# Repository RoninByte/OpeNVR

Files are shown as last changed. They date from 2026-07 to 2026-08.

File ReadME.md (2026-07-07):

BOARD STATUS: In Production

Photo's of the PCB;







Features:

M-Key M.2 PCIe Gen 3 X2 Slot

E-Key M.2 PCIe Gen 3 X1 Slot

2x 2.5GBe Ethernet Ports (Realtek's RTL8125BG-CG)

4x Molex Mini-Fit Jr for powering upto 3.5" Sata drives

5v Fan header for the built in fan on the Lattepanda MU

12v Fan Header for a system fan

HDMI 2.1

2x USB 3.2 Gen 2

2x USB 2.0

DDR4 SO-DIMM Slot for Lattepanda MU (Many options to choose from)

Uses Nano-ITX Standard

20v USB-C PD Input.

Dual Bios to switch between MU Bios and Your own Custom Bios

6x Sata Ports (ASM1166)

* 2 Sata ports will remain unpopulated however they will be connected to the IC incase you want to add more ports

Sata Ports LED (Once again optional)

Any Suggestions Just Open an Issue and i'll take a look

Credits:

EShark 

WifiCable for improvements and fixes

Lattepanda Team For Lattepanda MU Lite Kit

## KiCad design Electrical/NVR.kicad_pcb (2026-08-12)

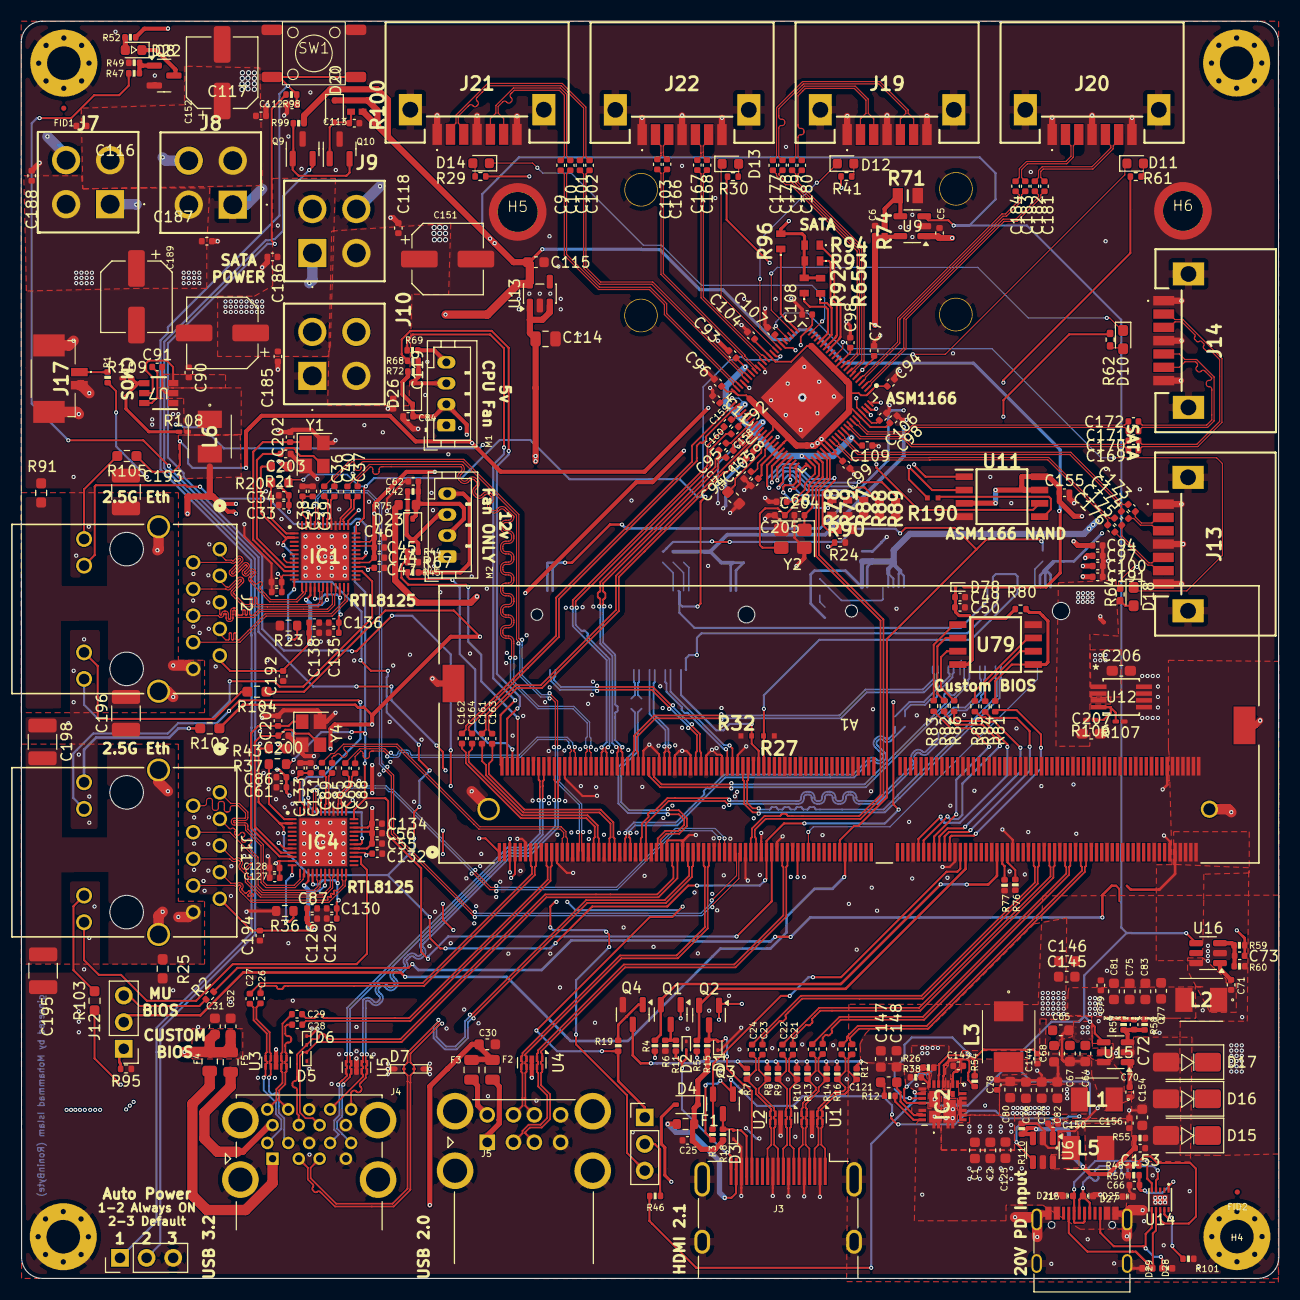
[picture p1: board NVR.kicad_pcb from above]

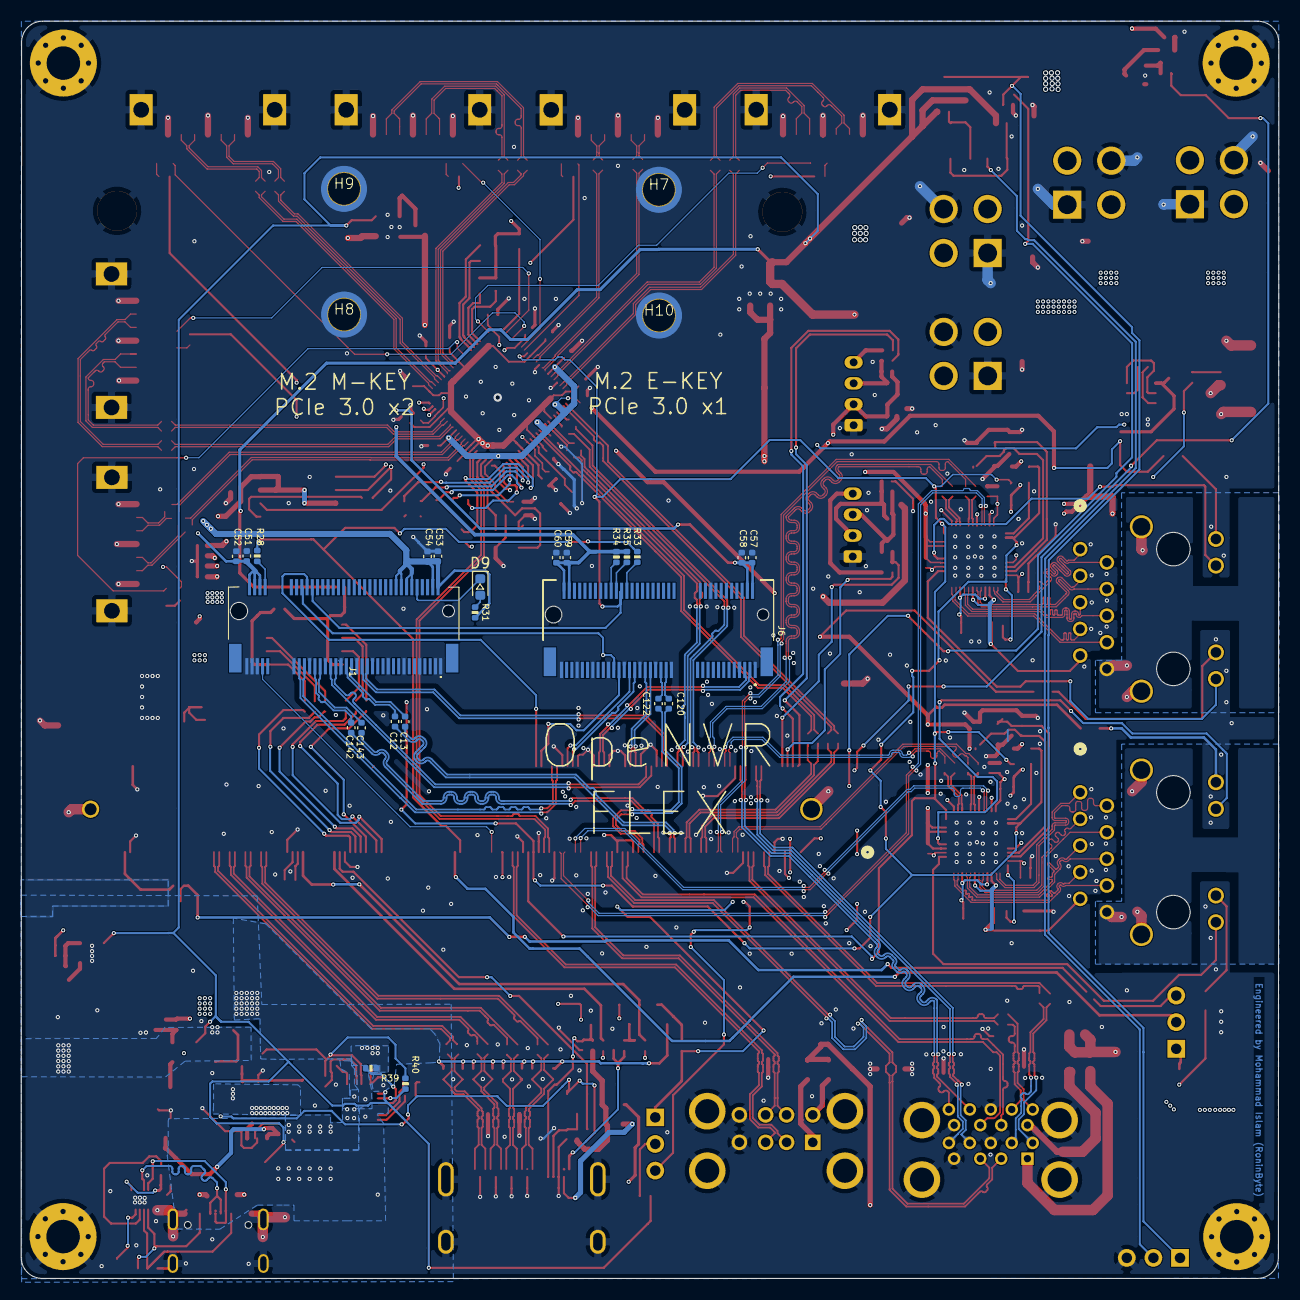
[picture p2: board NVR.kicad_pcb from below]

Board: 4 copper layers, 120.0 x 120.0 mm, 400 parts (28 on the bottom side), 317 nets.

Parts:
A1: TE Connectivity 2309413-1 DDR4 SODIMM H9.2mm; CONN260_2309413-1_TEC
C1, C2, C64, C65, C67, C68, C121: 22uF/50V; C_0603_1608Metric
C5, C6, C66, C112: 1uF/16V; C_0402_1005Metric
C7, C8, C11, C17, C18, C19, C20, C21, C22, C23, C24, C25, C26, C27, C28, C29, C52, C54, C58, C60, C62, C70, C71, C78, C79, C84, C91, C92, C93, C94#3, C106, C107, C108, C109, C116, C117, C118, C119, C150, C156, C185, C186, C187, C188: 100nF/50V; C_0402_1005Metric
C9, C103, C166, C167, C168, C169, C170, C171, C172, C173, C174, C175, C176, C177, C178, C179, C180, C181, C182, C183, C184: 10nF/20V; C_0402_1005Metric
C10, C101, C102: 10nF; C_0402_1005Metric
C12, C13, C120, C122, C142, C143: 220nF/50V; C_0402_1005Metric
C30, C31, C32, C74, C75, C76, C77, C80, C81, C82, C83: 22uF/10V; C_0603_1608Metric
C33, C34, C35, C36, C37, C38, C39, C40, C41, C42, C44, C45, C46, C47, C55, C56, C61, C69, C85, C86, C88, C89, C134, C135, C136, C137, C138, C192, C194: 100nF/50v; C_0402_1005Metric
C49: 22uF/6.3V; C_0402_1005Metric
C50: 0.1uF/16V; C_0402_1005Metric
C51, C53, C57, C59, C94, C94#2, C95, C96, C97, C98#2, C99, C100, C104, C113, C127, C128, C129, C130, C131, C133, C191: 10uF/10V; C_0402_1005Metric
C72, C73, C153: 12pF/50V; C_0402_1005Metric
C87, C98, C105, C126, C132: C; C_0402_1005Metric
C90: 10uF/50V; C_0402_1005Metric
C114: 10uF/50V; C_0805_2012Metric
C115: 10u/F10V; C_0603_1608Metric
C125: 100nF/50V; C_0603_1608Metric
C144: 1uF/25V; C_0402_1005Metric
C145, C146, C147, C148: 47uF; C_0603_1608Metric
C149: 4.7uF/25V; C_0402_1005Metric
C151, C152: 220uF/50V; CP_Elec_6.3x7.7
C154: 22uF/25V; C_0603_1608Metric
C155: 100uF/6.3V; C_0402_1005Metric
C157, C158, C159, C160, C161, C162, C163, C164: 220nF/10V; C_0402_1005Metric
C165: 4.7uF/1%; C_0603_1608Metric
C189, C190: 100uF/25V; CP_Elec_6.3x7.7
C193, C195, C196, C198: 2.2nF/2kv; C_1210_3225Metric_Pad1.33x2.70mm_HandSolder
C200, C201, C202, C203, C204, C205: 22pF/20V; C_0402_1005Metric
C206, C207: 2.2uF/25V; C_0603_1608Metric_Pad1.08x0.95mm_HandSolder
D1, D2, D3, D5, D6, D7, D8: ESD5V0B03; D_SOD-923
D4, D20, D23, D26: 1N5819WS; D_SOD-323
D9, D11, D12, D13, D14, D22: LED_G; LED_0603_1608Metric
D10, D18: LED_G; LED_0603_1608Metric_Pad1.05x0.95mm_HandSolder
D15, D16, D17: SS54; D_SMA
D21, D25: ESD5V0B03; D_0402_1005Metric
D27, D28, D29: PESD24VS1UL-N; D_0402_1005Metric
D78: D_Schottky; D_SOD-923
F1: 6V/50mA; R_0603_1608Metric
F2, F3: 6V/1A; Fuse_0805_2012Metric
F4: 6V/2A; R_0805_2012Metric
F5: 6V/2A; Fuse_0805_2012Metric
FID1, FID2: Fiducial; Fiducial_0.5mm_Mask1mm
H1, H2, H3, H4: MountingHole_Pad; MountingHole_3.2mm_M3_Pad_Via
H5, H6: MountingHole_Pad; MountingHole_3mm_M2_Pad_TopOnly
H7, H8, H9, H10: MountingHole_M2.0; MountingHole_3mm_M2_Pad_TopOnly
IC1, IC4: RTL8125BG-CG; QFN40P600X600X100-49N
IC2: SiC437AED-T1-GE3; SIC437DEDT1GE3
J1: Bus_M.2_Socket_M; PCIe_M.2_Connectors_P=0.5mm_H=4.2mm_KeyM
J2, J11: ARJM11A1-805-AB-EW2; ARJM11A1-805-AB-EW2_ABR
J3: HDMI_A; HDMI_A_Molex_208658-1001_Horizontal
J4: USB3_A_Stacked; USB3_A_Molex_48406-0001_Horizontal_Stacked
J5: USB_A_Stacked; USB_A_CUI_UJ2-ADH-TH_Horizontal_Stacked
J6: Bus_M.2_Socket_E; PCIe_M.2_Connectors_P=0.5mm_H=4.2mm_KeyE
J7, J8, J9, J10: 87427-0442; 874270442
J12, J15: Conn_01x03_Pin; PinHeader_1x03_P2.54mm_Vertical
J13, J14, J19, J20, J21, J22: SATA-A-PL-SMT-K; SATAAPLSMTK
J16: USB_C_Receptacle_USB2.0; USB_C_Receptacle_G-Switch_GT-USB-7010ASV
J17: 53261-0271; 532610271
JP1: Jumper_3_Bridged12; PinHeader_1x03_P2.54mm_Vertical
L1, L2, L5, L6: 2.2uH/4.3A; SPM4010-4020
L3: 1.5uH/14A; ETQ-P3M_KVP
M1, M2: Fan_4pin; JST_PH_B4B-PH-K_1x04_P2.00mm_Vertical
Q1, Q8, Q9, Q10: 2N7002; SOT-23
Q2, Q3, Q4: 2SK3018; SOT-23
R1, R11, R47, R50: 1K/1%; R_0402_1005Metric
R2, R34, R35, R48, R49, R54, R58, R60, R95, R110: 10K/1%; R_0402_1005Metric
R3, R5, R12, R15, R18, R19, R29, R30, R31, R41, R52, R61: 2.2K/1%; R_0402_1005Metric
R4: 1M/1%; R_0402_1005Metric
R6, R44, R67, R68: 21.5K/1%; R_0402_1005Metric
R7, R8, R9, R10, R13, R14, R16, R17: 470R/1%; R_0402_1005Metric
R20, R37: 1K/1%; R_0603_1608Metric
R21, R43: 4.7K/1%; R_0603_1608Metric
R23, R36: 2.49K/1%; R_0603_1608Metric
R24: RC0402FR-075KL; R_0402_1005Metric
R25, R91: 1M/1%; R_0603_1608Metric_Pad0.98x0.95mm_HandSolder
R26: 1.0K/1%; R_0402_1005Metric
R27, R32, R190: ERA-2AEB3321X; ERA2AED122X
R28, R33: 0R/1%; R_0402_1005Metric
R38: 19.1K/1%; R_0402_1005Metric
R39: 200K/1%; R_0402_1005Metric
R40: 499K/1%; R_0402_1005Metric
R42, R72: 4.7K/1%; R_0402_1005Metric
R45, R46, R69, R98: 100R/1%; R_0402_1005Metric
R55: 240K/1%; R_0402_1005Metric
R57: 75K/1%; R_0402_1005Metric
R59: 45K/1%; R_0402_1005Metric
R62, R64: 2.2K/1%; R_0402_1005Metric_Pad0.72x0.64mm_HandSolder
R65, R78, R79, R87, R88, R89, R90, R92, R93, R94, R96: ERA-3AED162V; ERA3AEB101V
R71: CPF0805B25KE1; RESC2012X65N
R74: CRCW040250K0FKED; RESC1005X40N
R75: 0R/1%; R_0603_1608Metric
R76, R77, R99: 100K/1%; R_0402_1005Metric
R80, R101: 120K/1%; R_0402_1005Metric
R81: 0R; R_0402_1005Metric
R82, R83, R84, R85, R86: 15R/1%; R_0402_1005Metric
R100: RC0402FR-071ML; RESC1005X40N
R102, R103, R104, R105: 1k/1%; R_0603_1608Metric_Pad0.98x0.95mm_HandSolder
R106: 3.16K/1%; R_0201_0603Metric_Pad0.64x0.40mm_HandSolder
R107, R109: 10.1K/1%; R_0201_0603Metric_Pad0.64x0.40mm_HandSolder
R108: 2.37K/1%; R_0201_0603Metric_Pad0.64x0.40mm_HandSolder
SW1: SW_Push; SW_Push_6x6x6
U1, U2: TPAZ1023-04F; Diodes_UDFN-10_1.0x2.5mm_P0.5mm
U3, U4, U5: ULC0524P; Diodes_UDFN-10_1.0x2.5mm_P0.5mm
U6, U15, U16: SY8253ADC; TSOT-23-6
U7: TPS562201DDCR; DDC0006A_N
U8: ASM1166; QFN-88_L10.0-W10.0-P0.40-BL-EP5.6
U9: SOT-23-5
U11, U79: W25Q128JVSIQ; SOIC127P790X216-8N
U12: ADP1715ARMZ-R7; RM_8_ADI
U13: NCP718xSN300; SOT-23-5
U14: CH224Q_C46061833; DFN-10_L2.0-W2.0-P0.40-BL-EP
Y1, Y2, Y4: 25MHz; Crystal_SMD_3225-4Pin_3.2x2.5mm

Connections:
5V_HDMI_VCC: C25.1, D4.1 (K), F1.1, R15.1, R18.1
+0V9: C35.2, C38.2, C41.2, C42.2, C47.2, C127.2, C128.2, C129.1, C130.1, C131.2, C132.2, C133.2, C135.1, C136.1, IC1.8 (DVDD09_1), IC1.11 (AVDD09_1), IC1.16 (AVDD09_2), IC1.22 (AVDD09_3), IC1.28 (DVDD09_2), IC1.37 (EVDD09), IC1.47 (DVDD09_3), IC4.8 (DVDD09_1), IC4.11 (AVDD09_1), IC4.16 (AVDD09_2), IC4.22 (AVDD09_3), IC4.28 (DVDD09_2), IC4.37 (EVDD09), IC4.47 (DVDD09_3), L6.2
+1V0: C94.2, C94#2.2, C94#3.2, C95.2, C96.2, C97.2, C98.2, C98#2.2, C99.2, C100.2, C104.2, C191.2, C207.1, R106.2, U8.1 (VDD105), U8.11 (VDD105), U8.32 (VDD105), U8.44 (VDD105), U8.50 (VDD105), U8.56 (VDD105), U8.60 (VDD105), U8.73 (VDD105), U8.74 (VDD105), U8.84 (VDD105), U12.3 (OUT)
+2V5: C6.1, C7.2, C8.2, C11.2, C92.2, C93.1, C109.2, R74.1, U8.6 (VCC25), U8.38 (VCC25), U8.47 (VCC25P), U8.53 (VCC25P), U8.68 (VCC25CK), U8.79 (VCC25), U9.5 (VOUT)
+3V3: C5.2, C33.2, C34.2, C44.2, C45.2, C46.2, C51.2, C52.2, C53.2, C54.2, C55.2, C56.2, C57.2, C58.2, C59.2, C60.2, C61.2, C73.1, C75.2, C77.2, C79.1, C81.2, C83.2, C86.2, C87.1, C105.2, C106.2, C107.2, C108.2, C126.1, C134.2, C137.1, C138.1, C155.1, C192.2, C194.2, C206.1, IC1.15 (AVDD33_1), IC1.19 (AVDD33_2), IC1.29 (DVDD33_1), IC1.33 (AVDD33_3), IC1.34 (AVDD33_XTAL), IC1.43 (EVDD33), IC1.46 (DVDD33_2), IC4.15 (AVDD33_1), IC4.19 (AVDD33_2), IC4.29 (DVDD33_1), IC4.33 (AVDD33_3), IC4.34 (AVDD33_XTAL), IC4.43 (EVDD33), IC4.46 (DVDD33_2), J1.2 (3.3V), J1.4 (3.3V), J1.12 (3.3V), J1.14 (3.3V), J1.16 (3.3V), J1.18 (3.3V), J1.70 (3.3V), J1.72 (3.3V), J1.74 (3.3V), J2.9 (VCC), J6.2 (3.3V), J6.4 (3.3V), J6.72 (3.3V), J6.74 (3.3V), J11.9 (VCC), L2.2, Q1.1 (G), Q2.1 (G), Q3.1 (G), R3.1, R4.1, R5.1, R29.2, R30.2, R31.2, R34.2, R35.1, R41.2, R52.2, R59.2, R61.2, R62.2, R64.2, R65.2, R92.2, R93.2, R94.2, R96.2, R102.1, R103.1, R104.1, R105.1, U8.22 (VCC33), U8.28 (VCC33), U8.58 (VCC33), U8.85 (VCC33), U9.1 (VIN), U11.3 (IO2), U11.7 (IO3), U11.8 (VCC), U12.1 (EN), U12.2 (IN)
+3V3_SB: C115.1, D20.1 (K), D78.2 (A), IC2.19 (EN), R21.1, R43.1, R46.2, R99.2, R100.2, U6.4 (EN), U9.3 (EN), U13.5 (OUT), U15.4 (EN), U16.4 (EN)
+5V: C30.2, C31.2, C32.2, C72.1, C74.2, C76.2, C78.1, C80.2, C82.2, C84.1, C90.2, C185.1, C186.1, C187.1, C188.1, C189.1, C190.1, D4.2 (A), D26.1 (K), F2.1, F3.1, F4.1, F5.1, J7.2, J8.2, J9.2, J10.2, L1.2, M1.2 (+), R57.2, R72.1, U7.3 (VIN), U7.5 (EN)
+12V: C116.1, C117.1, C118.1, C119.1, C145.1, C146.1, C147.1, C148.1, C151.1, C152.1, IC2.18 (VOUT), J7.3, J8.3, J9.3, J10.3, L3.1, R38.2, R75.2
+15V: C153.1, C154.2, C156.1, D15.2 (A), D16.2 (A), D17.2 (A), L5.2, R55.2
+20V: C1.1, C2.1, C114.1, C125.1, D27.1 (K), IC2.1 (VIN_1), IC2.2 (VIN_2), IC2.22 (VIN_3), IC2.26 (VIN_4), J16.A4 (VBUS), J16.A9 (VBUS), J16.B4 (VBUS), J16.B9 (VBUS), R48.1, R50.1, U6.5 (VIN), U13.1 (IN), U13.3 (EN)
+BATT: A1.115 (VBAT), R1.1
/BIOS/SPI-CS: A1.165 (~SPI_CS), R81.1
/BIOS/SPI-IO0: A1.159 (SPI_MOSI/SPI_IO0), R83.1
/BIOS/SPI-IO1: A1.163 (SPI_MISO/SPI_IO1), R84.1
/BIOS/SPI-IO2: A1.161 (SPI_IO2), R85.1
/BIOS/SPI-IO3: A1.153 (SPI_IO3), R86.1
/BIOS/SPI_CLK: A1.155 (SPI_CLK), R82.1
/Fan_Temp/FAN_1_PWM: A1.2 (FAN1_PWM), R69.1
/Fan_Temp/FAN_1_TAC: A1.4 (FAN1_TAC), R68.2
/Fan_Temp/FAN_2_PWM: A1.6 (FAN2_PWM), R45.1
/Fan_Temp/FAN_2_TAC: A1.8 (FAN2_TAC), R44.2, R67.1
/Gigabit Ethernet/GbE_PCIe_0_RX+: A1.28 (HSIO2_RX+), C88.1
/Gigabit Ethernet/GbE_PCIe_0_RX-: A1.30 (HSIO2_RX-), C69.1
/Gigabit Ethernet/GbE_PCIe_0_TX+: A1.25 (HSIO2_TX+), C85.1
/Gigabit Ethernet/GbE_PCIe_0_TX-: A1.27 (HSIO2_TX-), C89.1
/Gigabit Ethernet/GbE_PCIe_1_RX+: A1.34 (HSIO3_RX+), C37.1
/Gigabit Ethernet/GbE_PCIe_1_RX-: A1.36 (HSIO3_RX-), C40.1
/Gigabit Ethernet/GbE_PCIe_1_TX+: A1.31 (HSIO3_TX+), C36.1
/Gigabit Ethernet/GbE_PCIe_1_TX-: A1.33 (HSIO3_TX-), C39.1
/Gigabit Ethernet/GbE_PCIe_CLK0+: A1.85 (REFCLK0+), IC4.44 (REFCLK_P)
/Gigabit Ethernet/GbE_PCIe_CLK0-: A1.87 (REFCLK0-), IC4.45 (REFCLK_N)
/Gigabit Ethernet/HSI_0+: C36.2, IC1.41 (HSIP)
/Gigabit Ethernet/HSI_0-: C39.2, IC1.42 (HSIN)
/Gigabit Ethernet/HSI_1+: C85.2, IC4.41 (HSIP)
/Gigabit Ethernet/HSI_1-: C89.2, IC4.42 (HSIN)
/Gigabit Ethernet/HSO_0+: C37.2, IC1.38 (HSOP)
/Gigabit Ethernet/HSO_0-: C40.2, IC1.39 (HSON)
/Gigabit Ethernet/HSO_1+: C88.2, IC4.38 (HSOP)
/Gigabit Ethernet/HSO_1-: C69.2, IC4.39 (HSON)
/Gigabit Ethernet/LED0: IC4.30 (LED0/EEDI/SPISI/SDA), J11.12 (CATHODE)
/Gigabit Ethernet/LED0_ETH1: IC1.30 (LED0/EEDI/SPISI/SDA), J2.12 (CATHODE)
/Gigabit Ethernet/LED1: IC4.27 (LED1/EESK/SPISCK), J11.14 (CATHODE)
/Gigabit Ethernet/LED1_ETH1: IC1.27 (LED1/EESK/SPISCK), J2.14 (CATHODE)
/Gigabit Ethernet/MDI0+: IC1.13 (MDIP0), J2.1 (TD1+)
/Gigabit Ethernet/MDI0-: IC1.14 (MDIN0), J2.2 (TD1-)
/Gigabit Ethernet/MDI1+: IC1.17 (MDIP1), J2.3 (TD2+)
/Gigabit Ethernet/MDI1-: IC1.18 (MDIN1), J2.4 (TD2-)
/Gigabit Ethernet/MDI2+: IC1.20 (MDIP2), J2.5 (TD3+)
/Gigabit Ethernet/MDI2-: IC1.21 (MDIN2), J2.6 (TD3-)
/Gigabit Ethernet/MDI3+: IC1.23 (MDIP3), J2.7 (TD4+)
/Gigabit Ethernet/MDI3-: IC1.24 (MDIN3), J2.8 (TD4-)
/Gigabit Ethernet/MDI_0+: IC4.13 (MDIP0), J11.1 (TD1+)
/Gigabit Ethernet/MDI_0-: IC4.14 (MDIN0), J11.2 (TD1-)
/Gigabit Ethernet/MDI_1+: IC4.17 (MDIP1), J11.3 (TD2+)
/Gigabit Ethernet/MDI_1-: IC4.18 (MDIN1), J11.4 (TD2-)
/Gigabit Ethernet/MDI_2+: IC4.20 (MDIP2), J11.5 (TD3+)
/Gigabit Ethernet/MDI_2-: IC4.21 (MDIN2), J11.6 (TD3-)
/Gigabit Ethernet/MDI_3+: IC4.23 (MDIP3), J11.7 (TD4+)
/Gigabit Ethernet/MDI_3-: IC4.24 (MDIN3), J11.8 (TD4-)
/Gigabit Ethernet/~WAKE: IC1.2 (LANWAKEB), IC4.2 (LANWAKEB), R21.2, R43.2
/HDMI/DDC_SCL: D1.2 (A2), J3.15 (SCL), Q2.3 (D), R15.2
/HDMI/DDC_SDA: D3.2 (A2), J3.16 (SDA), Q3.3 (D), R18.2
/HDMI/DDI_B_DDC_SCL: A1.171 (DDIB_DDC_SCL), Q2.2 (S), R5.2
/HDMI/DDI_B_DDC_SDA: A1.169 (DDIB_DDC_SDA), Q3.2 (S), R3.2
/HDMI/DDI_B_HPD: A1.183 (DDIB_HPD), Q1.2 (S), R4.2
/HDMI/DDI_B_TX0+: A1.217 (DDIB_TX0+), C17.1
/HDMI/DDI_B_TX0-: A1.215 (DDIB_TX0-), C18.1
/HDMI/DDI_B_TX1+: A1.211 (DDIB_TX1+), C19.1
/HDMI/DDI_B_TX1-: A1.209 (DDIB_TX1-), C20.1
/HDMI/DDI_B_TX2+: A1.205 (DDIB_TX2+), C21.1
/HDMI/DDI_B_TX2-: A1.203 (DDIB_TX2-), C22.1
/HDMI/DDI_B_TX3+: A1.199 (DDIB_TX3+), C23.1
/HDMI/DDI_B_TX3-: A1.197 (DDIB_TX3-), C24.1
/HDMI/HPD: D2.2 (A2), J3.19 (HPD), R11.2
/HDMI/TMDS_CK+: C23.2, J3.10 (CK+), R8.1, U2.4, U2.7 (NC)
/HDMI/TMDS_CK-: C24.2, J3.12 (CK-), R7.1, U2.5, U2.6 (NC)
/HDMI/TMDS_D0+: C21.2, J3.7 (D0+), R10.1, U2.1, U2.10 (NC)
/HDMI/TMDS_D0-: C22.2, J3.9 (D0-), R9.1, U2.2, U2.9 (NC)
/HDMI/TMDS_D1+: C19.2, J3.4 (D1+), R14.1, U1.4, U1.7 (NC)
/HDMI/TMDS_D1-: C20.2, J3.6 (D1-), R13.1, U1.5, U1.6 (NC)
/HDMI/TMDS_D2+: C17.2, J3.1 (D2+), R17.1, U1.1, U1.10 (NC)
/HDMI/TMDS_D2-: C18.2, J3.3 (D2-), R16.1, U1.2, U1.9 (NC)
/LattePanda Module/HSIO_0_TX+: A1.13 (HSIO0_TX+), C27.1
/LattePanda Module/HSIO_0_TX-: A1.15 (HSIO0_TX-), C26.1
/LattePanda Module/HSIO_1_TX+: A1.19 (HSIO1_TX+), C29.1
/LattePanda Module/HSIO_1_TX-: A1.21 (HSIO1_TX-), C28.1
/LattePanda Module/HSIO_6_RX+: A1.64 (HSIO6_RX+), J6.41 (PERp0)
/LattePanda Module/HSIO_6_RX-: A1.66 (HSIO6_RX-), J6.43 (PERn0)
/LattePanda Module/HSIO_6_TX+: A1.61 (HSIO6_TX+), C120.1
/LattePanda Module/HSIO_6_TX-: A1.63 (HSIO6_TX-), C122.1
/LattePanda Module/HSIO_8_RX+: A1.40 (HSIO8_RX+), C159.2
/LattePanda Module/HSIO_8_RX-: A1.42 (HSIO8_RX-), C158.2
/LattePanda Module/HSIO_8_TX+: A1.37 (HSIO8_TX+), C162.1, C162.2
/LattePanda Module/HSIO_8_TX-: A1.39 (HSIO8_TX-), C164.1, C164.2
/LattePanda Module/HSIO_9_RX+: A1.46 (HSIO9_RX+), C160.2
/LattePanda Module/HSIO_9_RX-: A1.48 (HSIO9_RX-), C157.2
/LattePanda Module/HSIO_9_TX+: A1.43 (HSIO9_TX+), C161.1, C161.2
/LattePanda Module/HSIO_9_TX-: A1.45 (HSIO9_TX-), C163.1, C163.2
/LattePanda Module/HSIO_10_RX+: A1.52 (HSIO10_RX+), J1.29 (PERn1)
/LattePanda Module/HSIO_10_RX-: A1.54 (HSIO10_RX-), J1.31 (PERp1)
/LattePanda Module/HSIO_10_TX+: A1.49 (HSIO10_TX+), C13.1
/LattePanda Module/HSIO_10_TX-: A1.51 (HSIO10_TX-), C12.1
/LattePanda Module/HSIO_11_RX+: A1.58 (HSIO11_RX+), J1.43 (PERp0/SATA-B-)
/LattePanda Module/HSIO_11_RX-: A1.60 (HSIO11_RX-), J1.41 (PERn0/SATA-B+)
/LattePanda Module/HSIO_11_TX+: A1.55 (HSIO11_TX+), C143.1
/LattePanda Module/HSIO_11_TX-: A1.57 (HSIO11_TX-), C142.1
/LattePanda Module/REFCLK2+: A1.97 (REFCLK2+), U8.71 (PECLKP)
/LattePanda Module/REFCLK2-: A1.99 (REFCLK2-), U8.72 (PECLKN)
/LattePanda Module/REFCLK3+: A1.88 (REFCLK3+), J6.47 (REFCLKp0)
/LattePanda Module/REFCLK3-: A1.90 (REFCLK3-), J6.49 (REFCLKn0)
/LattePanda Module/REFCLK4+: A1.94 (REFCLK4+), J1.55 (REFCLKp)
/LattePanda Module/REFCLK4-: A1.96 (REFCLK4-), J1.53 (REFCLKn)
/LattePanda Module/SATAXPCIE_0: A1.119 (GPP_E0), J1.69 (PEDET)
/LattePanda Module/SLS_S3: A1.7 (SLS_S3), JP1.3 (B)
/LattePanda Module/SUSCLK_WIFI: A1.131 (SUSCLK), R28.2, R33.2
/LattePanda Module/USB_2_P7+: A1.76 (USB2_P7+), J6.3 (USB_D+)
/LattePanda Module/USB_2_P7-: A1.78 (USB2_P7-), J6.5 (USB_D-)
/LattePanda Module/~CLKREQE: A1.100 (~CLKREQ3), J6.53 (~CLKREQ0), R32.2
/LattePanda Module/~CLKREQM: A1.102 (~CLKREQ4), J1.52 (~CLKREQ), R27.2
/LattePanda Module/~PWR_SW: A1.1 (~PWRBTN), R98.2
/M.2 E&M Key/CON_PCIE_TX_0+: C13.2, J1.35 (PETn1)
/M.2 E&M Key/CON_PCIE_TX_0-: C12.2, J1.37 (PETp1)
/M.2 E&M Key/CON_PCIE_TX_1+: C143.2, J1.47 (PETn0/SATA-A-)
/M.2 E&M Key/CON_PCIE_TX_1-: C142.2, J1.49 (PETp0/SATA-A+)
/M.2 E&M Key/CON_PCIE_TX_2+: C120.2, J6.35 (PETp0)
/M.2 E&M Key/CON_PCIE_TX_2-: C122.2, J6.37 (PETn0)
/PCIe to SATA/LED_0: D14.1 (K), U8.21 (LED_S0)
/PCIe to SATA/LED_1: D13.1 (K), U8.30 (LED_S1)
/PCIe to SATA/LED_2: D12.1 (K), U8.29 (LED_S2)
/PCIe to SATA/LED_3: D11.1 (K), U8.26 (LED_S3)
/PCIe to SATA/LED_4: D10.1 (K), U8.24 (LED_S4)
/PCIe to SATA/LED_5: D18.1 (K), U8.13 (LED_S5)
/PCIe to SATA/RX_N_0: C10.2, U8.42 (SRXN0)
/PCIe to SATA/RX_N_1: C167.2, U8.34 (SRXN1)
/PCIe to SATA/RX_N_2: C178.2, U8.9 (SRXN2)
/PCIe to SATA/RX_N_3: C182.2, U8.3 (SRXN3)
/PCIe to SATA/RX_N_4: C171.2, U8.82 (SRXN4)
/PCIe to SATA/RX_N_5: C175.2, U8.76 (SRXN5)
/PCIe to SATA/RX_P_0: C9.2, U8.43 (SRXP0)
/PCIe to SATA/RX_P_1: C168.2, U8.33 (SRXP1)
/PCIe to SATA/RX_P_2: C177.2, U8.10 (SRXP2)
/PCIe to SATA/RX_P_3: C181.2, U8.2 (SRXP3)
/PCIe to SATA/RX_P_4: C172.2, U8.83 (SRXP4)
/PCIe to SATA/RX_P_5: C176.2, U8.75 (SRXP5)
/PCIe to SATA/TX_N_0: C101.2, U8.40 (STXN0)
/PCIe to SATA/TX_N_1: C166.2, U8.36 (STXN1)
/PCIe to SATA/TX_N_2: C179.2, U8.8 (STXN2)
/PCIe to SATA/TX_N_3: C183.2, U8.4 (STXN3)
/PCIe to SATA/TX_N_4: C170.2, U8.81 (STXN4)
/PCIe to SATA/TX_N_5: C174.2, U8.77 (STXN5)
/PCIe to SATA/TX_P_0: C102.2, U8.39 (STXP0)
/PCIe to SATA/TX_P_1: C103.2, U8.37 (STXP1)
/PCIe to SATA/TX_P_2: C180.2, U8.7 (STXP2)
/PCIe to SATA/TX_P_3: C184.2, U8.5 (STXP3)
/PCIe to SATA/TX_P_4: C169.2, U8.80 (STXP4)
/PCIe to SATA/TX_P_5: C173.2, U8.78 (STXP5)
/PSU/CC1: D28.1 (K), J16.A5 (CC1), U14.7 (CC1)
/PSU/CC2: D29.1 (K), J16.B5 (CC2), U14.6 (CC2)
/PSU/PWR_C_D+: D25.2 (A2), J16.A6 (D+), J16.B6 (D+), U14.4 (DP)
/PSU/PWR_C_D-: D21.2 (A2), J16.A7 (D-), J16.B7 (D-), U14.5 (DM)
/USB2.0&USB3.0/CON_USB1_D_N: A1.109 (USB2_P5-), J5.2 (D1-), U4.2, U4.9 (NC)
/USB2.0&USB3.0/CON_USB1_D_P: A1.111 (USB2_P5+), J5.3 (D1+), U4.1, U4.10 (NC)
/USB2.0&USB3.0/CON_USB2_D_N: A1.79 (USB2_P3-), J5.6 (D2-), U4.5, U4.6 (NC)
/USB2.0&USB3.0/CON_USB2_D_P: A1.81 (USB2_P3+), J5.7 (D2+), U4.4, U4.7 (NC)
/USB2.0&USB3.0/CON_USB3_D_N: A1.73 (USB2_P2-), D8.2 (A2), J4.2 (D1-)
/USB2.0&USB3.0/CON_USB3_D_P: A1.75 (USB2_P2+), D7.2 (A2), J4.3 (D1+)
/USB2.0&USB3.0/CON_USB3_SSRX_N: A1.18 (HSIO0_RX-), J4.5 (SSRX1-), U5.4, U5.7 (NC)
/USB2.0&USB3.0/CON_USB3_SSRX_P: A1.16 (HSIO0_RX+), J4.6 (SSRX1+), U5.5, U5.6 (NC)
/USB2.0&USB3.0/CON_USB3_SSTX_N: C26.2, J4.8 (SSTX1-), U3.4, U3.7 (NC)
/USB2.0&USB3.0/CON_USB3_SSTX_P: C27.2, J4.9 (SSTX1+), U3.5, U3.6 (NC)
/USB2.0&USB3.0/CON_USB4_D_N: A1.67 (USB2_P1-), D6.2 (A2), J4.11 (D2-)
/USB2.0&USB3.0/CON_USB4_D_P: A1.69 (USB2_P1+), D5.2 (A2), J4.12 (D2+)
/USB2.0&USB3.0/CON_USB4_SSRX_N: A1.24 (HSIO1_RX-), J4.14 (SSRX2-), U5.1, U5.10 (NC)
/USB2.0&USB3.0/CON_USB4_SSRX_P: A1.22 (HSIO1_RX+), J4.15 (SSRX2+), U5.2, U5.9 (NC)
/USB2.0&USB3.0/CON_USB4_SSTX_N: C28.2, J4.17 (SSTX2-), U3.1, U3.10 (NC)
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

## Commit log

2025-08-31 Add initial files
    [HDMI.kicad_sch, LattePanda Module.kicad_sch, M.2 E&M Key.kicad_sch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]
2025-08-31 switch to 5v power plane
    [BIOS.kicad_sch, Gigabit Ethernet.kicad_sch, NVR.kicad_pcb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]
2025-08-31 add crystal for rp2040 and update readme
    [NVR.kicad_pcb, PSU.kicad_sch]
2025-09-01 switch to 20V PD input
    [LattePanda Module.kicad_sch, NVR.kicad_pcb, NVR.kicad_sch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]
2025-09-04 replace the 12v buck with a 12 amp capable buck
    also removed soft start circuit because its built in the Buck Converter IC
    [NVR.kicad_pcb, PCIe to sata.kicad_sch, PSU.kicad_sch]
2025-09-23 Add step down converter
    Prevent 20v going into the lattepanda mu, it has been stepped down to 15v
    [NVR.kicad_pcb, PCIe to sata.kicad_sch, PSU.kicad_sch]
2026-02-12 Major Overhaul
    [Gigabit Ethernet.kicad_sch, LattePanda Module.kicad_sch, M.2 E&M Key.kicad_sch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]
2026-02-12 Relocate 1v0 PMIC
    [NVR.kicad_pcb]
2026-02-12 Fix Ground Plane Intteruptions
    [Gigabit Ethernet.kicad_sch, NVR.kicad_pcb]
2026-02-12 Fix Further Ground Plane Intteruptions
    [NVR.kicad_pcb]
2026-06-03 Update Board According to DFA Review
    Updated Ethernet Jack
    Updated L3 Inductor
    Fixed a few errors
    Updated mounting hole size
    [BIOS.kicad_sch, Gigabit Ethernet.kicad_sch, HDMI.kicad_sch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]
2026-06-06 further changes required by DFA review
    [LattePanda Module.kicad_sch, NVR.kicad_pcb, PSU.kicad_sch]
2026-06-10 Further DFA Changes
    Changed RJ45 jack to one capable of 10gbps, to remove any possible bottleneck
    [Gigabit Ethernet.kicad_sch, NVR.kicad_pcb]
2026-06-10 remove unused component schematics
    [Security.kicad_sch]
2026-06-10 Update PCB Photos
2026-06-10 add another PCB Photo
2026-06-12 Add board status to ReadME
2026-06-12 Update some information on the board
2026-07-07 changed ethernet port
    changed to one that has built in magnetics
    [Gigabit Ethernet.kicad_sch, NVR.kicad_pcb]
2026-07-07 update board info
2026-07-08 further updates
    split the ground plane for the sic437
    use ethernet port that is available for purchase easily
    [Gigabit Ethernet.kicad_sch, NVR.kicad_pcb, PSU.kicad_sch]
2026-07-11 further updates
    [Gigabit Ethernet.kicad_sch, NVR.kicad_pcb]
2026-07-21 add some fixes from initial prototype and fix 1v0 regulator
    [Gigabit Ethernet.kicad_sch, LattePanda Module.kicad_sch, NVR.kicad_pcb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]
2026-07-21 update 0.9v regulator
    [PSU.kicad_sch]
2026-07-21 Revert "update 0.9v regulator"
    This reverts commit 20026994f1eba6e61bd33e858c390714c2ea728b.
    [PSU.kicad_sch]
2026-07-21 better implementation of 0.95v
    [NVR.kicad_pcb, PSU.kicad_sch]
2026-08-12 Update Board Further
    [NVR.kicad_pcb, PSU.kicad_sch]
